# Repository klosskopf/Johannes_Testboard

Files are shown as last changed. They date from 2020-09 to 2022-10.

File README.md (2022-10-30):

# ECP5_Breakout_with_DDR2  
A LFE5U-25F68G256CFDG Breakout board with DDR2 x8 and Spi-Flash  
  
This breakout board is meant to be capable of running Linux (No idea if thats the case)  
  
### It features:  
-LFE55U-25F68G256CFDG FPGA  
-E1109AFGB 1Gbit DDR2 (desoldered from a DIMM)  
-W25Q128FV 128Mbit QSPI-Flash  
-44 GPIO Pins  

### Programming
I usually use a Altera-USB blaster as jtag cable.
That works pretty good, but I have to ignore a status bit during programmin
The programming-pinout on the board is:
|1|2||3|4|5|6|7|8|9|10|
|-|-|-|-|-|-|-|-|-|-|-|
|VIN(5V)|GND||VCC|TDO|TDI|NC|NC|TMS|GND|TCK|

This is the correct pinout for the USB ispDOWNLOAD Cable H-USBN-2A

Initial programming is done via JTAG (In my case ispDOWNLOAD Cable HW-USBN-2A))  
In future a "bootloader" should be built, to configure the Flash via serial  
  
**Do not expect this to be optimal.**  
**Do not expect this to be halfway decent.**  
**Do not expect this to work.**  
**Do not use this, but on your own risc**

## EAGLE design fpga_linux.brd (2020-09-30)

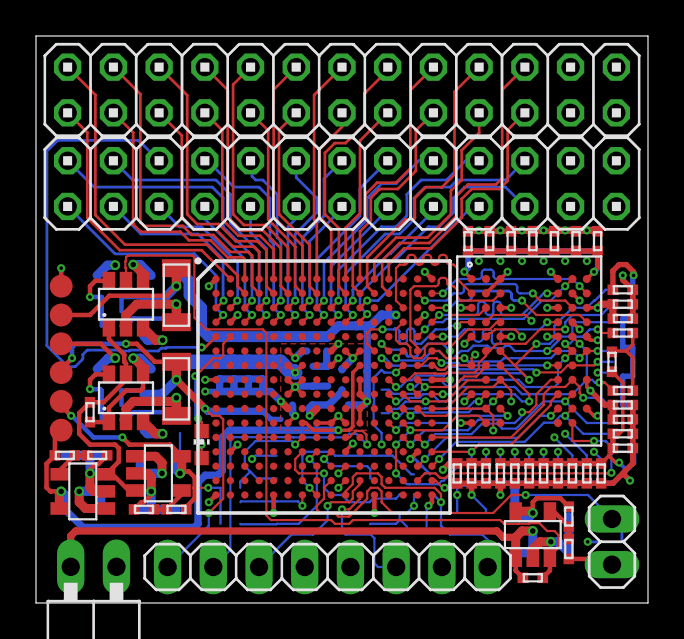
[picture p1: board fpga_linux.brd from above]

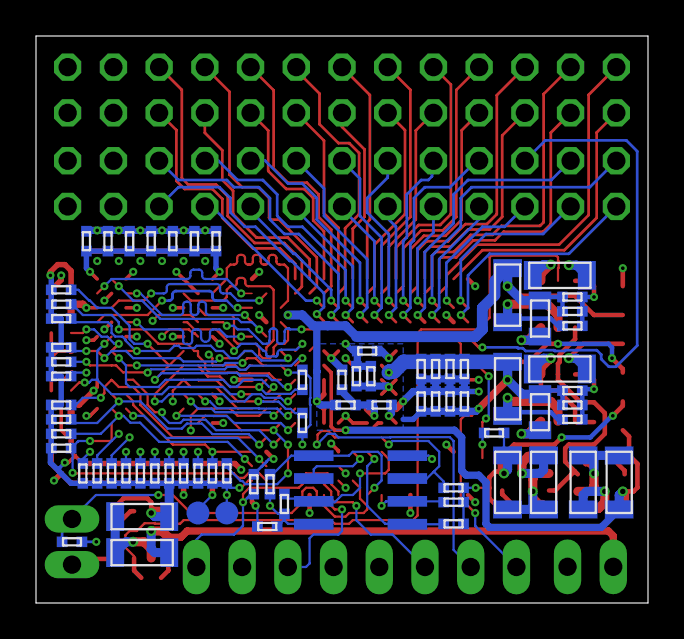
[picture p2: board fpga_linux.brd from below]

Board: 4 copper layers, 34.0 x 31.5 mm, 131 parts (74 on the bottom side), 110 nets.

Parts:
C1, C2, C3, C4, C5, C6, C7, C8, C9, C10, C11, C12, C13, C14, C15, C16, C17, C18, C19, C20, C21, C22, C23, C24, C25, C26, C27, C28, C29, C30, C31, C32, C33, C34, C35, C36, C37, C38, C39, C40, C41, C42, C43, C49, C50, C53, C54, C55: 0402
IC1: E1109AFGB; DDR2X8
IC2: LFE5U-25F68G256CFDG; BGA256C80P16X16_1400X1400X170
JP1: 1X08
JP2: 1X02
JP3, JP4: 2X13
LED1: CHIP-LED0603
POW:C1, POW:C2, POW:C4, POW:C5, POW:C7, POW:C8, POW:C9, POW:C11, POW:C12, POW:C13, POW:C14, POW:C15: 10u; 1206
POW:C3, POW:C10: 22p; 0402
POW:IC1, POW:IC4, POW:IC5: AP2127; SOT23-5
POW:IC2, POW:IC3: FP6373A; SOT23-6
POW:JP1: 1X02/90
POW:L1, POW:L2: 1u5; 0805
POW:R1: 56k2; 0402
POW:R2: 2k2; 0402
POW:R3, POW:R5, POW:R6: 18k; 0402
POW:R4: 38k3; 0402
POW:R7, POW:R9: 10k; 0402
POW:R10: 83k33; 0402
POW:R11, POW:R13: 100k; 0402
POW:R12: 200k; 0402
POW:TP1, POW:TP2, POW:TP3, POW:TP4, POW:TP5, POW:TP6, POW:TP7, POW:TP8: TPB1,27; B1,27
R1, R2, R8, R9, R10, R11, R12, R13, R14, R15, R16, R17, R18, R19, R20, R21, R22, R23, R24, R25, R26, R27, R28, R29, R30, R31, R32, R33: 0402
R3: 4k7; 0402
R4, R5, R6, R7: 10k; 0402
U$1: W25Q64FCSOIC8; SOIC8

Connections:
1V8: C3.2, C4.2, C5.2, C6.2, C7.2, C8.2, C9.2, C10.2, C11.2, C12.2, C13.2, C14.2, C15.2, C16.2, C17.2, C18.2, C19.2, C20.2, C21.2, C22.2, C23.2, C43.2, IC1.A1, IC1.A9, IC1.C1, IC1.C3, IC1.C7, IC1.C9, IC1.E1, IC1.E9, IC1.H9, IC1.L1, IC2.H11, IC2.J11, IC2.K11, IC2.L11, POW:C10.1, POW:C11.1, POW:C12.1, POW:L2.2, POW:R12.1, POW:TP2.TP
+3V3: C1.1, C49.2, C50.2, C53.2, C54.2, C55.2, IC2.F6, IC2.F7, IC2.F10, IC2.F11, IC2.H6, IC2.H7, IC2.J6, IC2.J7, IC2.L6, IC2.P10, JP3.25, JP3.26, JP4.25, JP4.26, POW:C1.1, POW:IC4.5, POW:R1.1, POW:TP5.TP, R3.1, R4.1, R5.1, R6.1, R7.1, R31.2, R33.1, U$1.8
FLASH_CLK: IC2.N9, U$1.6
FLASH_CS_N: IC2.N8, R3.2, U$1.1
FLASH_IO0: IC2.T8, R4.2, U$1.5
FLASH_IO1: IC2.T7, R5.2, U$1.2
FLASH_IO2: IC2.M7, R6.2, U$1.3
FLASH_IO3: IC2.N7, R7.2, U$1.7
GND: C1.2, C3.1, C4.1, C5.1, C6.1, C7.1, C8.1, C9.1, C10.1, C11.1, C12.1, C13.1, C14.1, C15.1, C16.1, C17.1, C18.1, C19.1, C20.1, C21.1, C22.1, C23.1, C24.1, C25.1, C26.1, C27.1, C28.1, C29.1, C30.1, C31.1, C32.1, C33.1, C34.1, C35.1, C36.1, C37.1, C38.1, C39.1, C40.1, C41.1, C42.1, C43.1, C49.1, C50.1, C53.1, C54.1, C55.1, IC1.A3, IC1.A7, IC1.B2, IC1.B8, IC1.D2, IC1.D8, IC1.E3, IC1.E7, IC1.J1, IC1.K9, IC2.A1, IC2.A16, IC2.D2, IC2.D15, IC2.F8, IC2.F9, IC2.G8, IC2.G10, IC2.H1, IC2.H8, IC2.H9, IC2.H10, IC2.H16, IC2.J8, IC2.J9, IC2.J10, IC2.K6, IC2.K7, IC2.K8, IC2.K9, IC2.K10, IC2.N2, IC2.N10, IC2.N15, IC2.R10, IC2.T1, IC2.T5, IC2.T12, IC2.T16, JP1.2, JP2.1, JP3.23, JP3.24, JP4.23, JP4.24, POW:C1.2, POW:C2.2, POW:C4.2, POW:C5.2, POW:C7.2, POW:C8.2, POW:C9.2, POW:C11.2, POW:C12.2, POW:C13.2, POW:C14.2, POW:C15.2, POW:IC1.2, POW:IC2.2, POW:IC3.2, POW:IC4.2, POW:IC5.2, POW:JP1.1, POW:R3.2, POW:R5.2, POW:R6.2, POW:R11.2, POW:R13.2, POW:TP6.TP, POW:TP8.TP, R32.1, U$1.4
LED_N: IC2.E2, LED1.C
unnamed: C2.2, R1.1, R30.1
unnamed: LED1.A, R33.2
PIN1: IC2.B3, JP4.2
PIN2: IC2.B4, JP4.4
PIN3: IC2.B5, JP4.6
PIN4: IC2.B6, JP4.8
PIN5: IC2.A6, JP4.10
PIN6: IC2.A7, JP4.12
PIN7: IC2.A8, JP4.14
PIN8: IC2.B10, JP4.16
PIN9: IC2.B11, JP4.18
PIN10: IC2.B12, JP4.20
PIN11: IC2.B13, JP4.22
PIN12: IC2.A2, JP4.1
PIN13: IC2.A3, JP4.3
PIN14: IC2.A4, JP4.5
PIN15: IC2.A5, JP4.7
PIN16: IC2.B7, JP4.9
PIN17: IC2.B8, JP4.11
PIN18: IC2.A9, JP4.13
PIN19: IC2.A10, JP4.15
PIN20: IC2.A11, JP4.17
PIN21: IC2.A12, JP4.19
PIN22: IC2.A13, JP4.21
PIN23: IC2.C3, JP3.2
PIN24: IC2.D4, JP3.4
PIN25: IC2.E1, JP3.6
PIN26: IC2.D5, JP3.8
PIN27: IC2.C5, JP3.10
PIN28: IC2.C6, JP3.12
PIN29: IC2.D7, JP3.14
PIN30: IC2.D8, JP3.16
PIN31: IC2.C8, JP3.18
PIN32: IC2.C9, JP3.20
PIN33: IC2.D10, JP3.22
PIN34: IC2.D1, JP3.1
PIN35: IC2.C1, JP3.3
PIN36: IC2.C2, JP3.5
PIN37: IC2.D3, JP3.7
PIN38: IC2.C4, JP3.9
PIN39: IC2.D6, JP3.11
PIN40: IC2.C7, JP3.13
PIN41: IC2.D9, JP3.15
PIN42: IC2.C10, JP3.17
PIN43: IC2.C11, JP3.19
PIN44: IC2.D11, JP3.21
POW:1V1UP: POW:IC1.3, POW:IC2.5, POW:IC3.1, POW:IC4.3, POW:R9.2
POW:1V8UP: POW:IC3.5, POW:IC5.3, POW:R7.2
POW:N$1: POW:IC1.4, POW:R4.2, POW:R5.1
POW:N$2: POW:IC3.3, POW:L2.1
POW:N$3: POW:C3.2, POW:IC2.6, POW:R10.2, POW:R11.1
POW:N$4: POW:IC2.3, POW:L1.1
POW:N$5: POW:IC4.4, POW:R1.2, POW:R3.1
POW:N$6: POW:IC5.4, POW:R2.2, POW:R6.1
POW:N$7: POW:C10.2, POW:IC3.6, POW:R12.2, POW:R13.1
RAM_A0: IC1.H8, IC2.M16, R23.2
RAM_A1: IC1.H3, IC2.K16, R22.2
RAM_A2: IC1.H7, IC2.M14, R21.2
RAM_A3: IC1.J2, IC2.K13, R20.2
RAM_A4: IC1.J8, IC2.M15, R19.2
RAM_A5: IC1.J3, IC2.K14, R18.2
RAM_A6: IC1.J7, IC2.N16, R17.2
RAM_A7: IC1.K2, IC2.K15, R16.2
RAM_A8: IC1.K8, IC2.P16, R15.2
RAM_A9: IC1.K3, IC2.L13, R14.2
RAM_A10: IC1.H2, IC2.J14, R13.2
RAM_A11: IC1.K7, IC2.P15, R12.2
RAM_A12: IC1.L2, IC2.L14, R11.2
RAM_A13: IC1.L8, IC2.R15, R10.2
RAM_BA0: IC1.G2, IC2.H15, R9.2
RAM_BA1: IC1.G3, IC2.J13, R8.2
RAM_BA2: IC1.G1, IC2.G16, R2.2
RAM_CAS_N: IC1.G7, IC2.G15, R26.2
RAM_CKE: IC1.F2, IC2.H14, R28.2
RAM_CK_N: IC1.F8, IC2.J15, R1.2
RAM_CK_P: IC1.E8, IC2.J16, R30.2
RAM_CS_N: IC1.G8, IC2.G13, R24.2
RAM_D0: IC1.C8, IC2.B15
RAM_D1: IC1.C2, IC2.D14
RAM_D2: IC1.D7, IC2.E16
RAM_D3: IC1.D3, IC2.F13
RAM_D4: IC1.D1, IC2.F12
RAM_D5: IC1.D9, IC2.C16
RAM_D6: IC1.B1, IC2.C14
RAM_D7: IC1.B9, IC2.B16
RAM_DM: IC1.B3, IC2.F15
RAM_DQS_N: IC1.A8, IC2.E15
RAM_DQS_P: IC1.B7, IC2.D16
RAM_ODT: IC1.F9, IC2.F16, R29.2
RAM_RAS_N: IC1.F7, IC2.F14, R25.2
RAM_WE_N: IC1.F3, IC2.H13, R27.2
RESET_N: IC2.R9, JP2.2, R31.1
TCK: IC2.T10, JP1.1, R32.2
TDI: IC2.R11, JP1.6
TDO: IC2.M10, JP1.7
TMS: IC2.T11, JP1.3
VCC: C30.2, C31.2, C37.2, C38.2, C39.2, C40.2, C41.2, C42.2, IC2.G6, IC2.G7, IC2.G9, IC2.L8, IC2.L9, IC2.L10, JP1.8, POW:C3.1, POW:C7.1, POW:C8.1, POW:L1.2, POW:R10.1, POW:TP3.TP
VCCAUX: IC2.G11, IC2.L7, POW:C13.1, POW:IC1.5, POW:R4.1, POW:TP4.TP
VIN: POW:C2.1, POW:C5.1, POW:C9.1, POW:C14.1, POW:C15.1, POW:IC1.1, POW:IC2.1, POW:IC2.4, POW:IC3.4, POW:IC4.1, POW:IC5.1, POW:JP1.2, POW:R7.1, POW:R9.1, POW:TP1.TP
VTT: C2.1, C24.2, C25.2, C26.2, C27.2, C28.2, C29.2, C32.2, C33.2, C34.2, C35.2, C36.2, IC1.E2, IC2.G14, IC2.R16, POW:C4.1, POW:IC5.5, POW:R2.1, POW:TP7.TP, R2.1, R8.1, R9.1, R10.1, R11.1, R12.1, R13.1, R14.1, R15.1, R16.1, R17.1, R18.1, R19.1, R20.1, R21.1, R22.1, R23.1, R24.1, R25.1, R26.1, R27.1, R28.1, R29.1

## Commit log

2020-09-29 Increased polygon isolation
    [fpga_linux.brd]
2020-09-29 Switched from vector font
    [fpga_linux.brd, fpga_linux.sch]
2020-09-29 adjusted DRAM model
    [fpga_linux.brd, fpga_linux.sch]
2020-09-30 Added gregs recommendations (pullup/down on grogramn/tck, usrled)
    [fpga_linux.brd, fpga_linux.sch]
2021-04-01 final commit
    [fpga_linux.brd, fpga_linux.sch]
